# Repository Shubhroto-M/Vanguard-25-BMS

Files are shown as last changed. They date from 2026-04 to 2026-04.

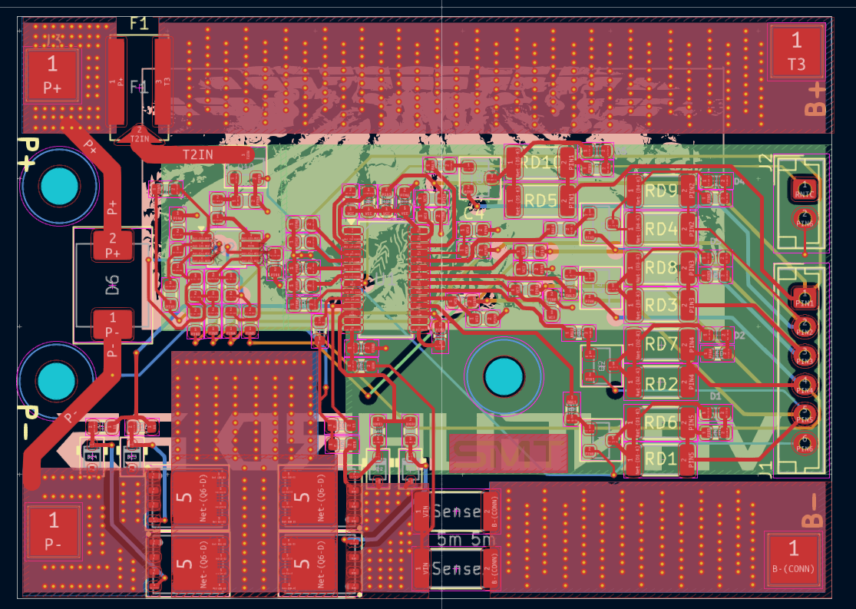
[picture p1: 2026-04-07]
Screenshot 2026-04-05 005611 - Copy (2).png

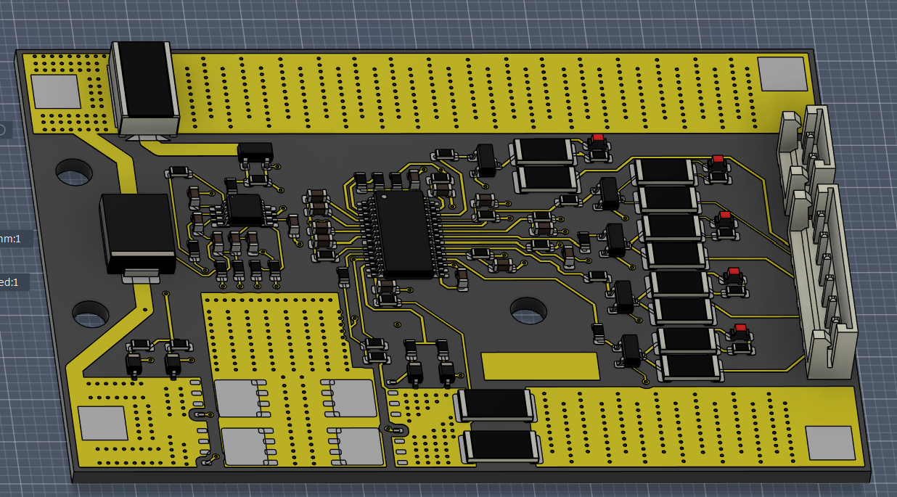
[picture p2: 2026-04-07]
Screenshot 2026-04-05 014049.png

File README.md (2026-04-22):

# 🐉 VANGUARD 25: Industrial-Grade 5S Battery Management System





> **Vanguard 25** is an open-source, high-current (20A) Battery Management System designed with strict, aerospace-style redundant safety architectures. It is built to handle massive current dumps while protecting lithium-ion chemistry from catastrophic failure modes.

*(Insert your best 3D Render of the top and bottom of the board here)*

## ⚡ Core Specifications
* **Architecture:** 5S (Configurable down to 3S/4S via hardware solder jumpers).
* **Operating Voltage:** 21V Max.
* **Current Capacity:** 25A Continuous / 45A Peak Over-current.
* **Balancing:** 150mA active hardware balancing per cell.
* **PCB Specs:** 2-Layer, standard 1oz/2oz copper, designed for Matte Black Solder Mask with ENIG (Gold) plating.

## 🛡️ Dual-Tier Safety Architecture
Unlike standard hobbyist BMS boards that rely on a single point of failure, Vanguard 25 implements a strictly hardware-based, dual-redundant safety net. **There is zero firmware to crash.**

1. **Primary Logic (BM3451):** Handles standard cell balancing, over-charge (OVP), over-discharge (UVP), and over-current protection.
2. **Redundant Failsafe (BQ771807):** The "Paranoia Chip." Runs on a completely independent internal voltage reference. If a cell hits a critical **4.5V hard cutoff**, it bypasses the main logic entirely.
3. **Hardware Kill Switch (Dexerials SKF-2045):** If the BQ771807 trips, it fires a voltage into the heater element of this chemical fuse, physically and permanently severing the main power line to prevent thermal runaway.

## 📐 Layout & Routing Strategy
* **Total Signal Isolation:** Massive, high-current copper polygons are restricted to the outer edges of the board. The sensitive analog measurement lines and logic ICs are grouped in a protected central island to prevent EMI and switching noise interference.
* **Thermal Management:** The parallel MOSFET bridge features aggressive thermal via stitching, allowing the internal and bottom copper planes to act as massive passive heatsinks during 25A continuous loads.
* **DRC Cleared:** 0 Errors, 0 Warnings under strict clearance constraints.

## 📁 Repository Contents
* `/KiCad_Project` - Full schematic and PCB layout files.
* `/Gerbers` - Production-ready manufacturing files.
* `/3D_Models` - STEP files for mechanical enclosure integration.

## ⚠️ DANGER & DISCLAIMER
**Lithium-Ion batteries contain massive amounts of energy and can cause fires, explosions, and severe injury if mishandled.**
This repository is provided as an open-source portfolio project and educational reference. It has not been tested by UL, CE, or any other regulatory body. If you choose to fabricate this board, populate the components, and connect it to live lithium cells, you do so entirely at your own risk. The designer takes absolutely zero responsibility for any damage to property, equipment, or persons. 

---
*Designed in Bengaluru.*

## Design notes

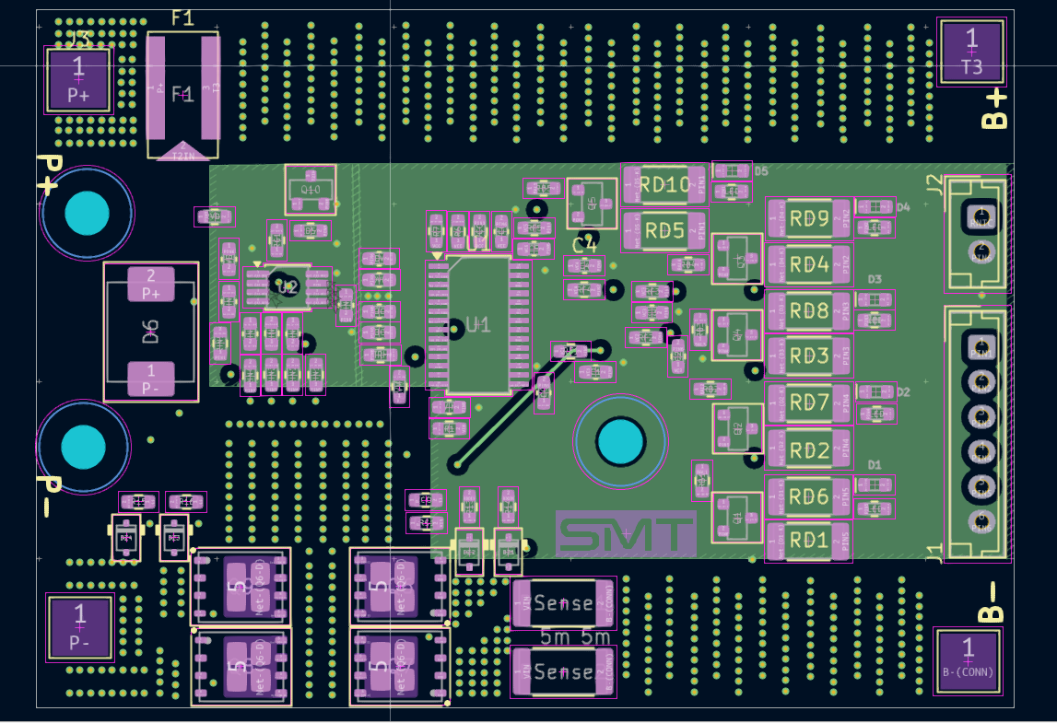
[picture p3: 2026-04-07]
Screenshot 2026-04-05 005637 - Copy - Copy.png

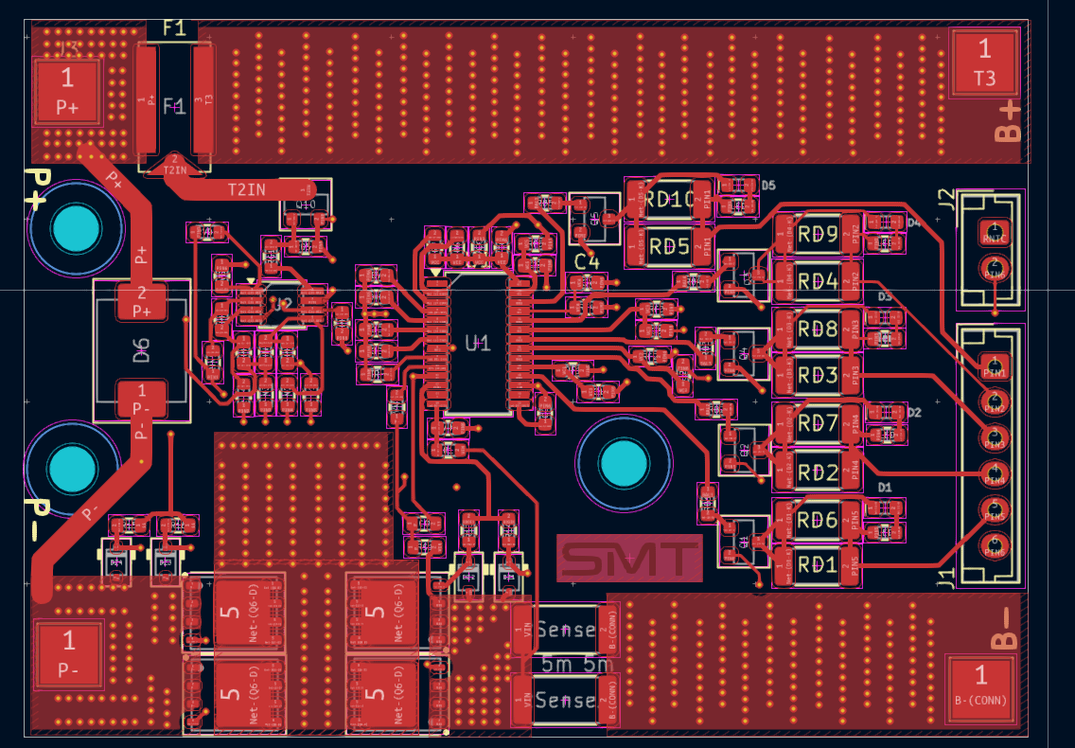
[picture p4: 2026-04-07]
Screenshot 2026-04-05 005628 - Copy - Copy.png

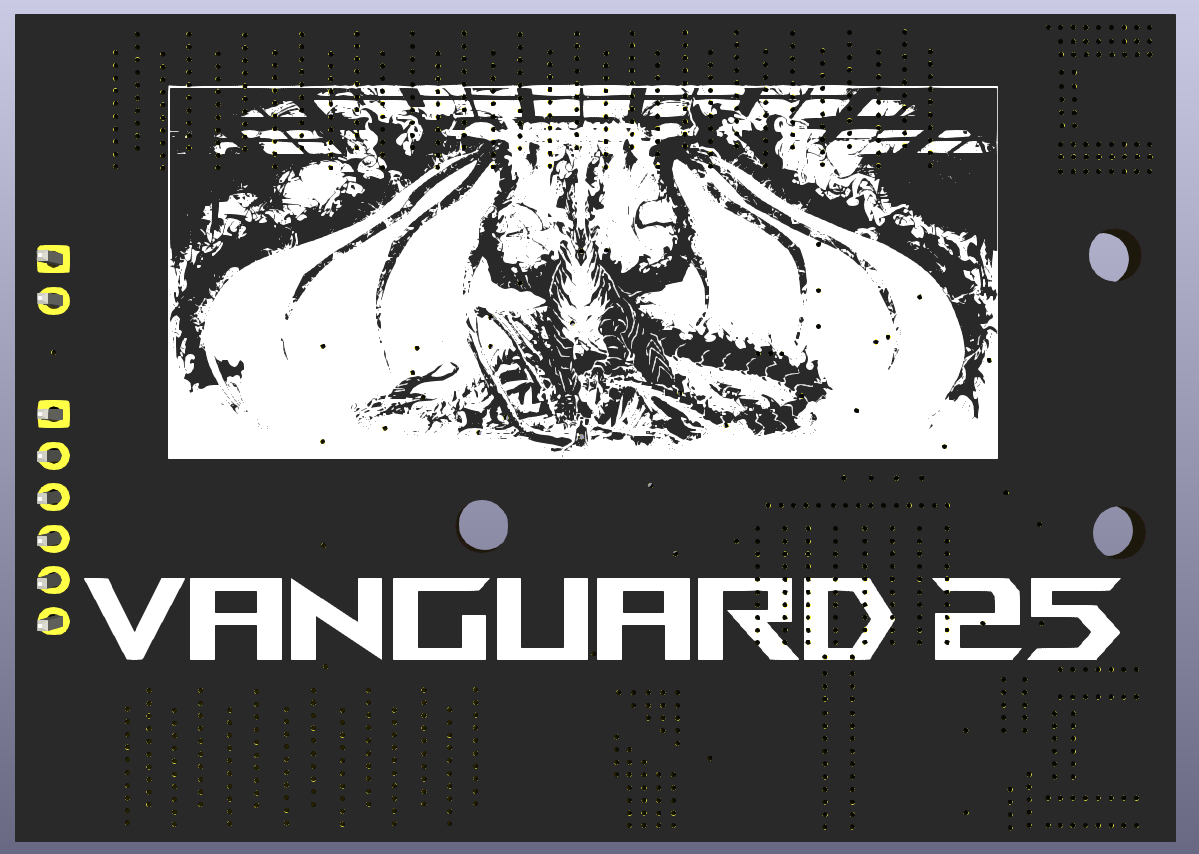
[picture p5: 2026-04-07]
Screenshot 2026-04-05 005559.png

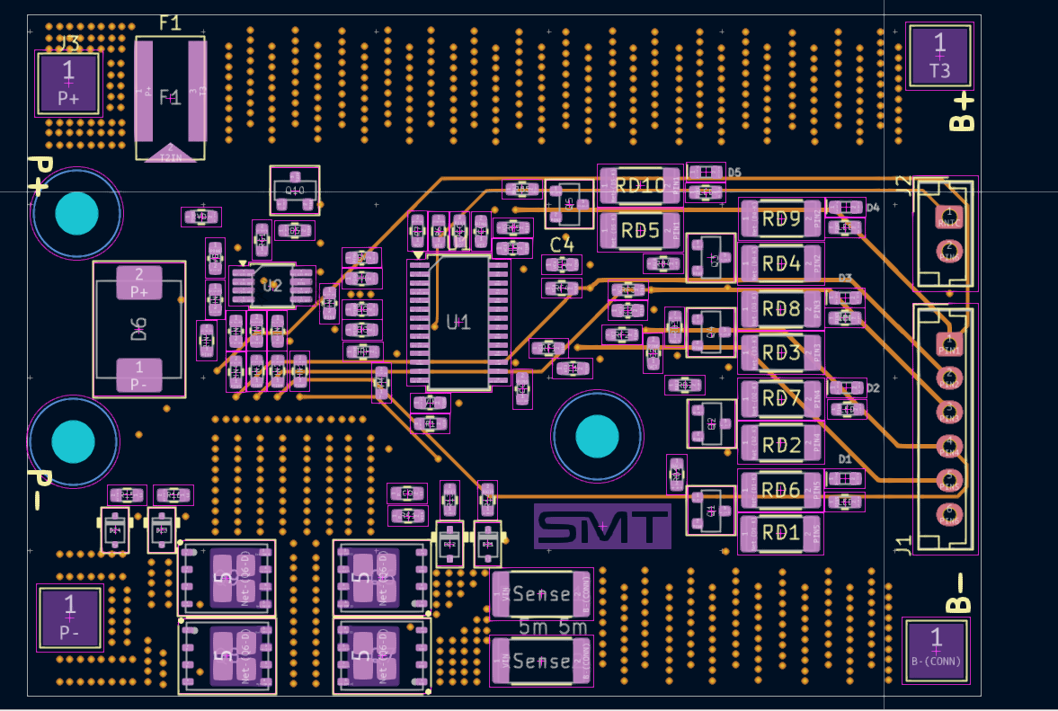
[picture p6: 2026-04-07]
Screenshot 2026-04-05 005645 - Copy.png

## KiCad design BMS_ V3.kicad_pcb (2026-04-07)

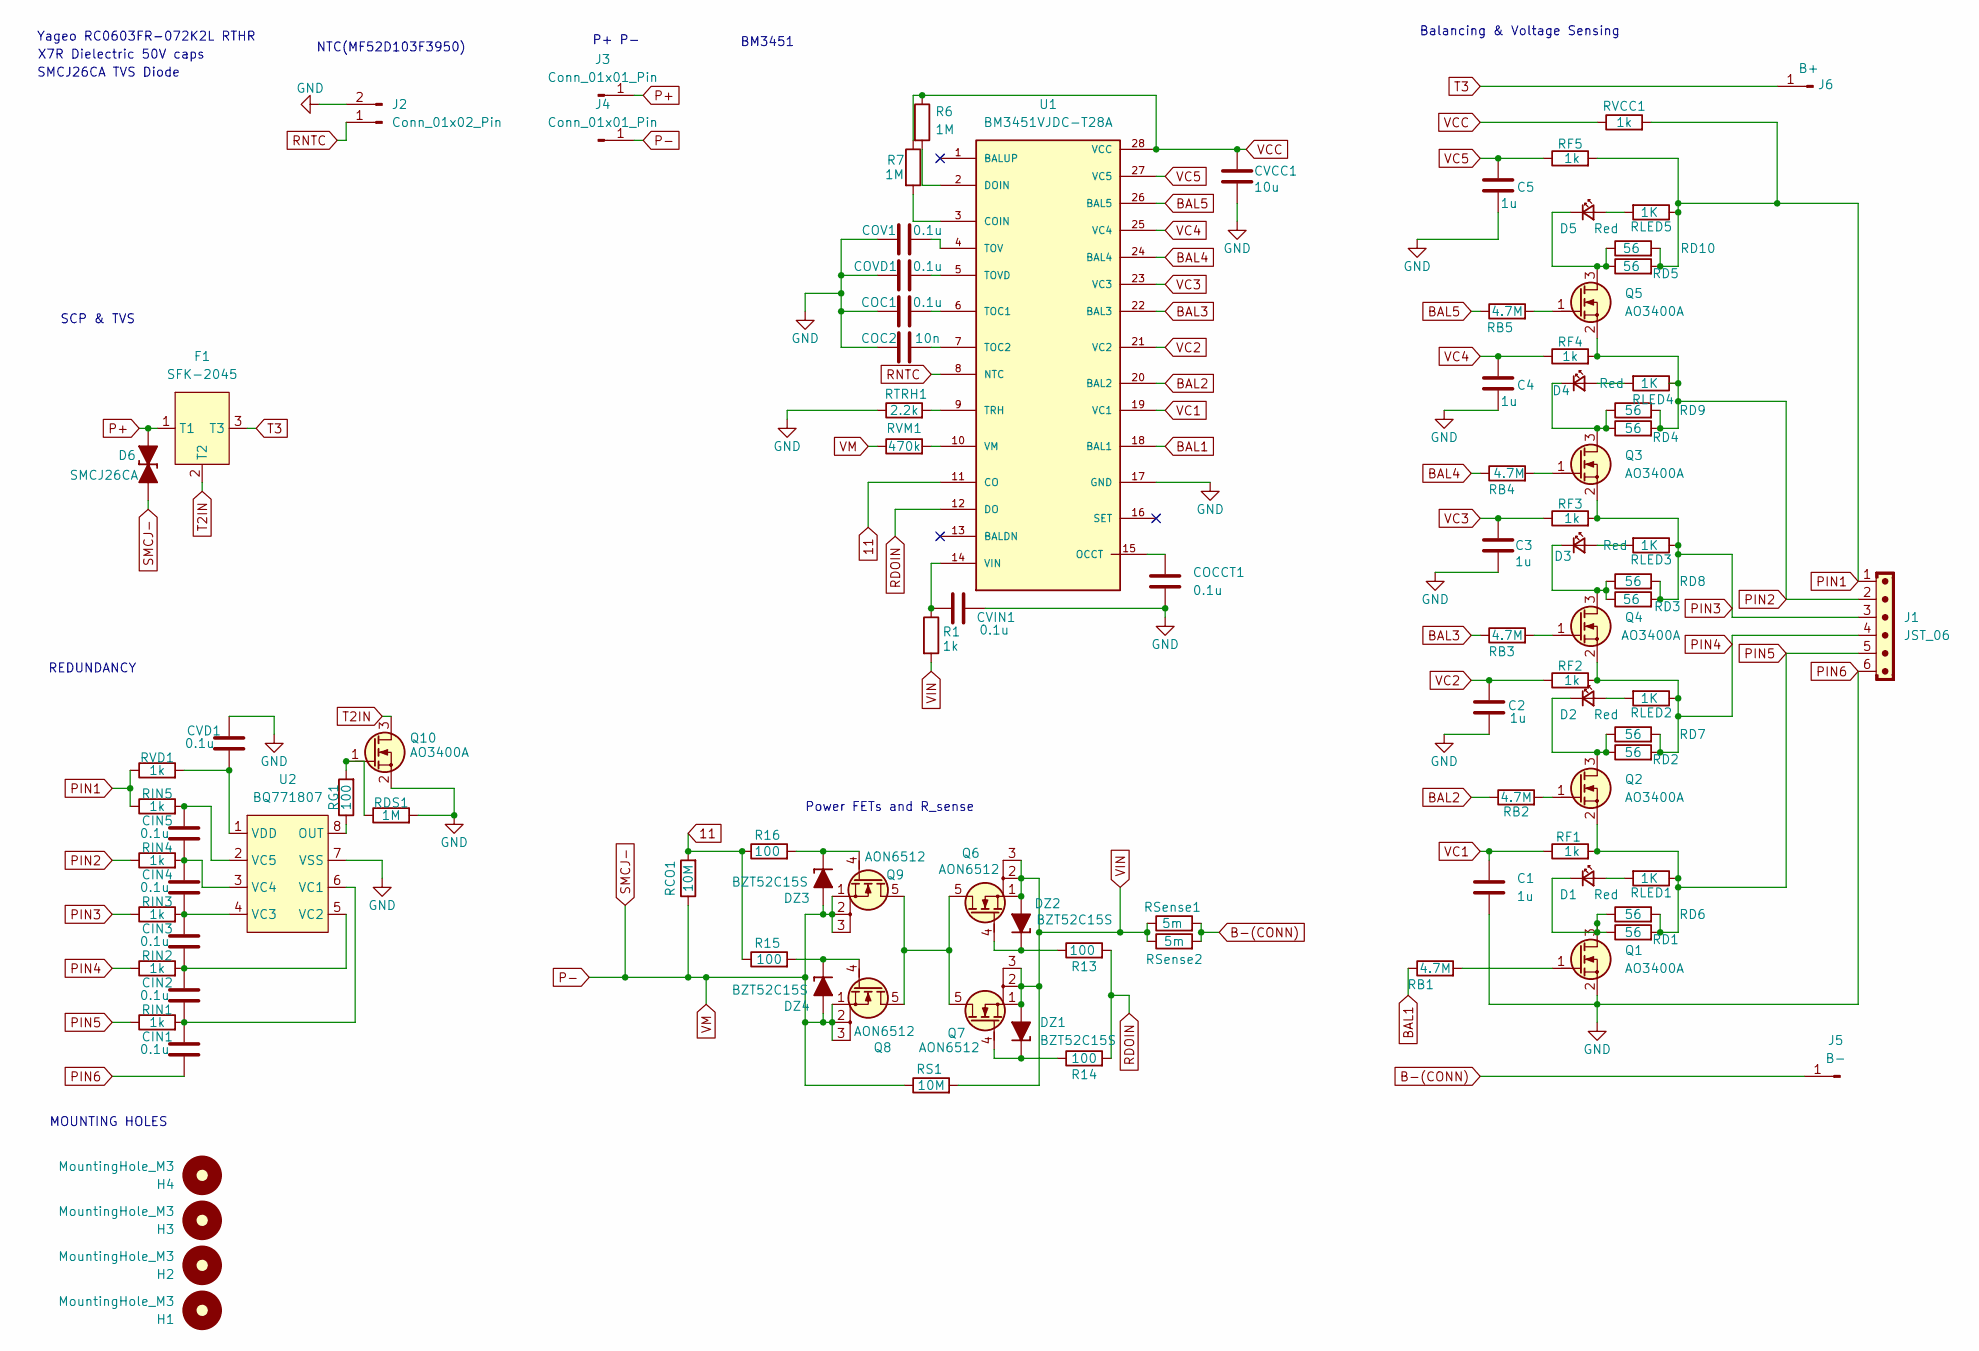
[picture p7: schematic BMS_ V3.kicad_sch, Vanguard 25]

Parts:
C1, C2, C3, C4, C5: 1u; C_0603_1608Metric
CIN1, CIN2, CIN3, CIN4, CIN5: 0.1u; C_0603_1608Metric
COC1: 0.1u; C_0603_1608Metric
COC2: 10n; C_0603_1608Metric
COCCT1: 0.1u; C_0603_1608Metric
COV1: 0.1u; C_0603_1608Metric
COVD1: 0.1u; C_0603_1608Metric
CVCC1: 10u; C_0603_1608Metric
CVD1: 0.1u; C_0603_1608Metric
CVIN1: 0.1u; C_0603_1608Metric
D1, D2, D3, D4, D5: Red; LED_0603_1608Metric_Red
D6: SMCJ26CA; D_SMC_TVS
DZ1, DZ2, DZ3, DZ4: BZT52C15S; D_SOD-323
F1: SFK-2045; SFK-2450
H1, H2, H3, H4: MountingHole_M3; MountingHole_3.2mm_M3
J1: JST_06; JST_EH_B6B-EH-A_1x06_P2.50mm_Vertical
J2: Conn_01x02_Pin; JST_EH_B2B-EH-A_1x02_P2.50mm_Vertical
J3, J4: Conn_01x01_Pin; TestPoint_Pad_4.0x4.0mm
J5: B-; TestPoint_Pad_4.0x4.0mm
J6: B+; TestPoint_Pad_4.0x4.0mm
Q1, Q2, Q3, Q4, Q5, Q10: AO3400A; SOT-23
Q6, Q7, Q8, Q9: AON6512; Infineon_PG-TDSON-8
R1: 1k; R_0603_1608Metric
R6, R7: 1M; R_0603_1608Metric
R13, R14, R15, R16: 100; R_0603_1608Metric
RB1, RB2, RB3, RB4, RB5: 4.7M; R_0603_1608Metric
RCO1: 10M; R_0603_1608Metric
RD1, RD2, RD3, RD4, RD5, RD6, RD7, RD8, RD9, RD10: 56; R_2010_5025Metric
RDS1: 1M; R_0603_1608Metric
RF1, RF2, RF3, RF4, RF5: 1k; R_0603_1608Metric
RG1: 100; R_0603_1608Metric
RIN1, RIN2, RIN3, RIN4, RIN5: 1k; R_0603_1608Metric
RLED1, RLED2, RLED3, RLED4, RLED5: 1K; R_0603_1608Metric
RS1: 10M; R_0603_1608Metric
RSense1, RSense2: 5m; R_2512_6332Metric
RTRH1: 2.2k; R_0603_1608Metric
RVCC1: 1k; R_0603_1608Metric
RVD1: 1k; R_0603_1608Metric
RVM1: 470k; R_0603_1608Metric
U1: BM3451VJDC-T28A; TSSOP-28_4.4x9.7mm_P0.65mm; PARTREV A/1
U2: BQ771807; VSSOP-8_3x3mm_P0.65mm

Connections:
11: R15.1, R16.1, RCO1.2, U1.11 (CO)
B-(CONN): J5.1, RSense1.2, RSense2.2
BAL1: RB1.1, U1.18 (BAL1)
BAL2: RB2.1, U1.20 (BAL2)
BAL3: RB3.1, U1.22 (BAL3)
BAL4: RB4.1, U1.24 (BAL4)
BAL5: RB5.1, U1.26 (BAL5)
unnamed: D1.2 (A), RLED1.2
unnamed: D1.1 (K), Q1.3 (D), RD1.1, RD6.1
unnamed: D2.2 (A), RLED2.2
unnamed: D2.1 (K), Q2.3 (D), RD2.1, RD7.1
unnamed: D3.2 (A), RLED3.2
unnamed: D3.1 (K), Q4.3 (D), RD3.1, RD8.1
unnamed: D4.2 (A), RLED4.2
unnamed: D4.1 (K), Q3.3 (D), RD4.1, RD9.1
unnamed: D5.2 (A), RLED5.2
unnamed: D5.1 (K), Q5.3 (D), RD5.1, RD10.1
unnamed: DZ1.1 (K), Q7.4 (G), R14.1
unnamed: DZ2.1 (K), Q6.4 (G), R13.1
unnamed: DZ3.1 (K), Q9.4 (G), R16.2
unnamed: DZ4.1 (K), Q8.4 (G), R15.2
unnamed: Q1.1 (G), RB1.2
unnamed: Q2.1 (G), RB2.2
unnamed: Q3.1 (G), RB4.2
unnamed: Q4.1 (G), RB3.2
unnamed: Q5.1 (G), RB5.2
unnamed: Q6.5 (D), Q7.5 (D), Q8.5 (D), Q9.5 (D)
unnamed: Q10.1 (G), RDS1.1, RG1.2
unnamed: R7.2, U1.3 (COIN)
unnamed: R6.2, U1.2 (DOIN)
unnamed: COCCT1.1, U1.15 (OCCT)
unnamed: COC1.2, U1.6 (TOC1)
unnamed: COC2.2, U1.7 (TOC2)
unnamed: COV1.2, U1.4 (TOV)
unnamed: COVD1.2, U1.5 (TOVD)
unnamed: RTRH1.2, U1.9 (TRH)
unnamed: CVIN1.1, R1.1, U1.14 (VIN)
unnamed: RVM1.2, U1.10 (VM)
unnamed: RG1.1, U2.8 (OUT)
unnamed: CIN1.1, CIN2.2, RIN1.2, U2.6 (VC1)
unnamed: CIN2.1, CIN3.2, RIN2.2, U2.5 (VC2)
unnamed: CIN3.1, CIN4.2, RIN3.2, U2.4 (VC3)
unnamed: CIN4.1, CIN5.2, RIN4.2, U2.3 (VC4)
unnamed: CIN5.1, RIN5.2, U2.2 (VC5)
unnamed: CVD1.2, RVD1.2, U2.1 (VDD)
P+: D6.2 (A), F1.1 (T1), J3.1
P-: D6.1 (K), DZ3.2 (A), DZ4.2 (A), J4.1, Q8.1 (S), Q8.2 (S), Q8.3 (S), Q9.1 (S), Q9.2 (S), Q9.3 (S), RCO1.1, RS1.1, RVM1.1
PIN1: J1.1, RD5.2, RD10.2, RF5.2, RIN5.1, RLED5.1, RVCC1.2, RVD1.1
PIN2: J1.2, Q5.2 (S), RD4.2, RD9.2, RF4.2, RIN4.1, RLED4.1
PIN3: J1.3, Q3.2 (S), RD3.2, RD8.2, RF3.2, RIN3.1, RLED3.1
PIN4: J1.4, Q4.2 (S), RD2.2, RD7.2, RF2.2, RIN2.1, RLED2.1
PIN5: J1.5, Q2.2 (S), RD1.2, RD6.2, RF1.2, RIN1.1, RLED1.1
PIN6: C1.2, C2.2, C3.2, C4.2, C5.2, CIN1.2, COC1.1, COC2.1, COCCT1.2, COV1.1, COVD1.1, CVCC1.2, CVD1.1, CVIN1.2, J1.6, J2.2, Q1.2 (S), Q10.2 (S), RDS1.2, RTRH1.1, U1.17 (GND), U2.7 (VSS)
RDOIN: R13.2, R14.2, U1.12 (DO)
RNTC: J2.1, U1.8 (NTC)
T2IN: F1.2 (T2), Q10.3 (D)
T3: F1.3 (T3), J6.1
VC1: C1.1, RF1.1, U1.19 (VC1)
VC2: C2.1, RF2.1, U1.21 (VC2)
VC3: C3.1, RF3.1, U1.23 (VC3)
VC4: C4.1, RF4.1, U1.25 (VC4)
VC5: C5.1, RF5.1, U1.27 (VC5)
VCC: CVCC1.1, R6.1, R7.1, RVCC1.1, U1.28 (VCC)
VIN: DZ1.2 (A), DZ2.2 (A), Q6.1 (S), Q6.2 (S), Q6.3 (S), Q7.1 (S), Q7.2 (S), Q7.3 (S), R1.2, RS1.2, RSense1.1, RSense2.1

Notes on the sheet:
MOUNTING HOLES
Power FETs and R_sense
Balancing & Voltage Sensing
P+ P-
SMCJ26CA TVS Diode
X7R Dielectric 50V caps
SCP & TVS
NTC(MF52D103F3950)
BM3451
Yageo RC0603FR-072K2L RTHR
REDUNDANCY

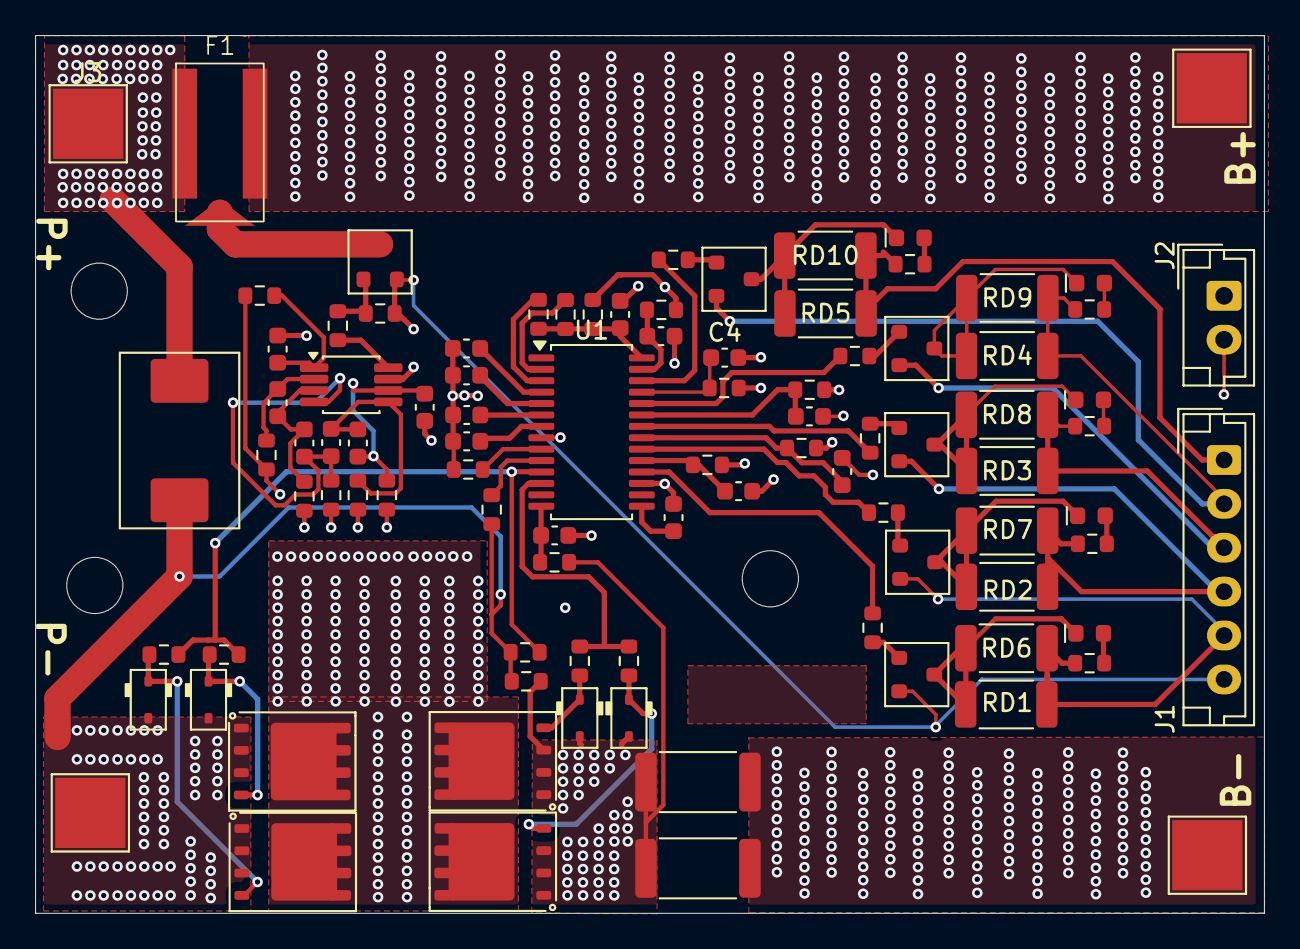
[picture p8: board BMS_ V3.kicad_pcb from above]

Board: 4 copper layers, 70.0 x 50.0 mm, 97 parts (0 on the bottom side), 64 nets.

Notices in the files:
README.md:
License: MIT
